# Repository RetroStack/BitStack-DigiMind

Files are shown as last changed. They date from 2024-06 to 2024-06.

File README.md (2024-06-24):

# DigiMind

As part of an introduction in digital electronics workshop at VCF SW 2024, I prepared this design of a Masterm\*nd like game to teach digital electronics.

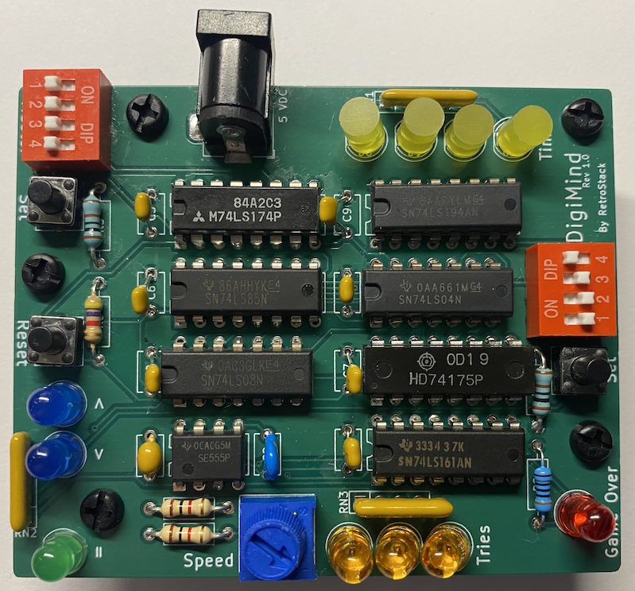
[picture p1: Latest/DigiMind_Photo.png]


## Latest Files

In the "Latest" folder, you'll find the most up-to-date design files, including:

- Gerber files suitable for popular online PCB manufacturers like [PCBWay](/Latest/DigiMind_Gerber_PCBWay.zip) and [JLCPCB](/Latest/DigiMind_Gerber_JLCPCB.zip). Most manufacturers should be fine with either.
- A Bill of Materials (BOM) in both [CSV](/Latest/DigiMind_BOM.csv) and [PDF](/Latest/DigiMind_BOM.pdf) formats.
- The [full schematics](/Latest/DigiMind_Schematics.pdf) of the board.

## Implementation

The board has been implemented using KiCAD 8. The KiCAD project files are included in this repository.

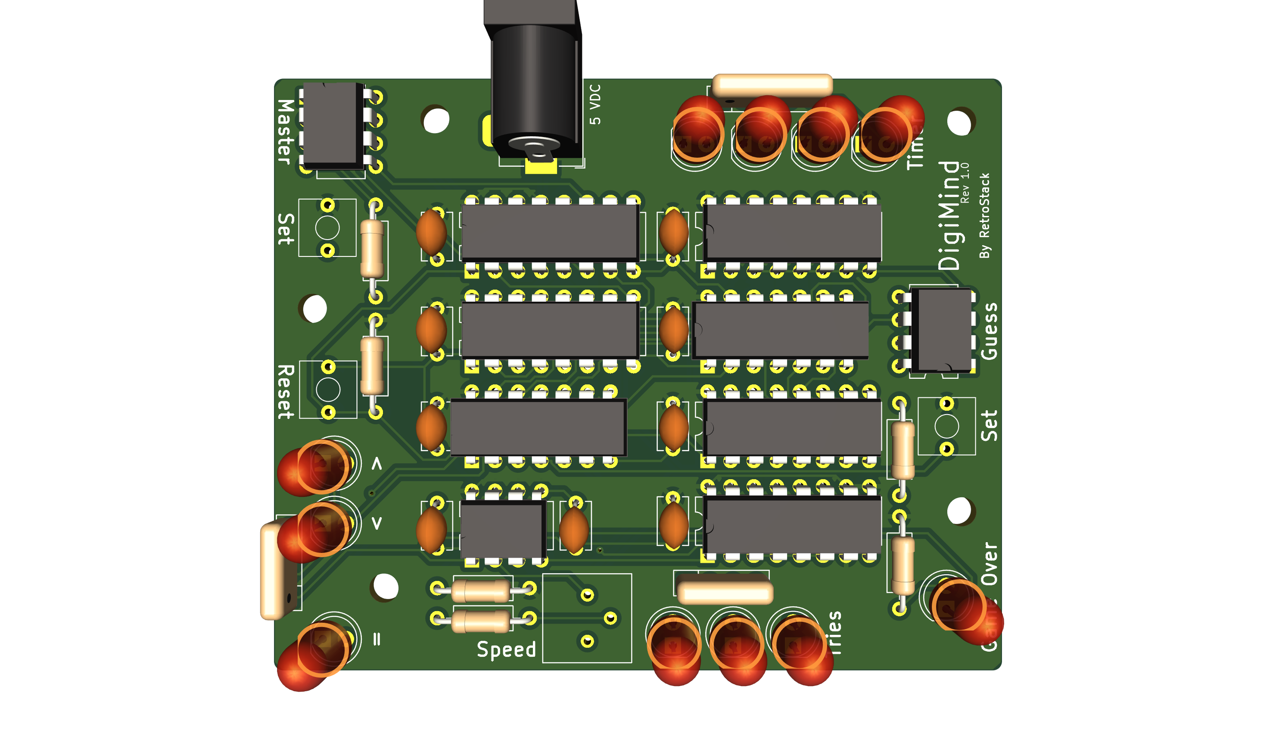
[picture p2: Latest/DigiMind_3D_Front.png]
Front

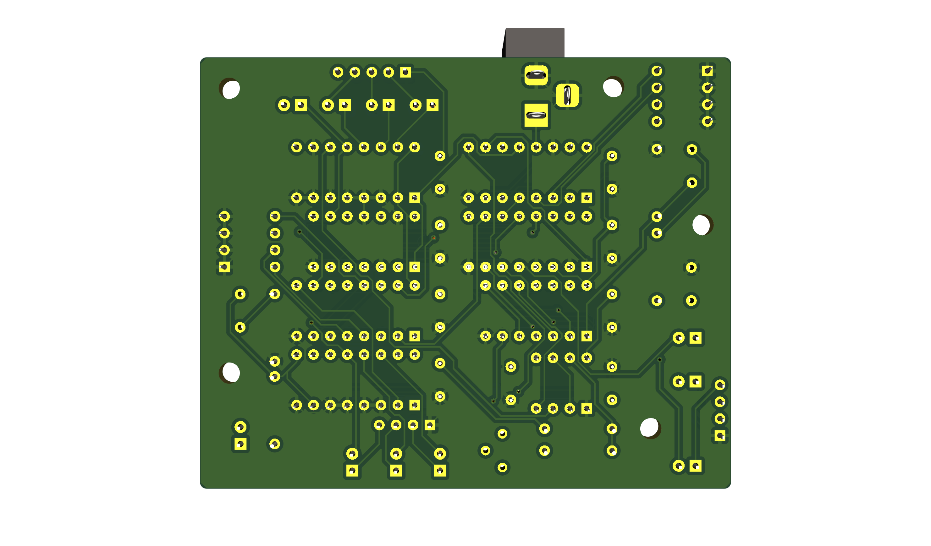
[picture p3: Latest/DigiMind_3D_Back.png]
Back


## How to Play

There are two players for this game:

- A person guessing the master code
- A person defining the master code

Before starting the game, the person defining the master code hits the "Reset" button to reset the game's state. Then, they enter the code using the DIP switches labeled "Master." When completed, the "Set" button must be pushed to set the master code. After that, the master code can be cleared from the DIP switches as it has been read into the memory.

As soon as the "Set" button is pressed, a timer labeled "Timer" starts running down. When the last light turns off, the game is over (if the master code was not found). The potentiometer labeled "Speed" can increase the time a player has to guess the master code.

The guesser needs to enter a code into the DIP switch on the other side, labeled "Guess." The "Set" button right next to it can be pressed to trigger a guess attempt. Each attempt is recognized and counted up with the "Tries" lights. When reaching a binary 8, the game is over.

In either case, when the time runs out or when 8 guesses have been made and the guess was wrong, the "Game Over" light indicates the game is over. This light will turn on regardless of whether the master code was found or not (to simplify the logic). What is important is the "=" light that indicates if the guess was correct.

If the guess was wrong, the board indicates if the master code is higher or lower than the entered guess. These indicators are labeled "<" and ">".

### Known Issues

Some decisions were made to keep the diagram somewhat readable for beginners. For example, the "Game Over" light will turn on regardless if the guess was found or not. There is also an issue when entering guesses where a bouncing of the "Set" button causes multiple guesses to register. This can be fixed by a debouncing circuit.

## Bill of Materials (BOM)

Below is a list of materials needed to assemble the PCB.

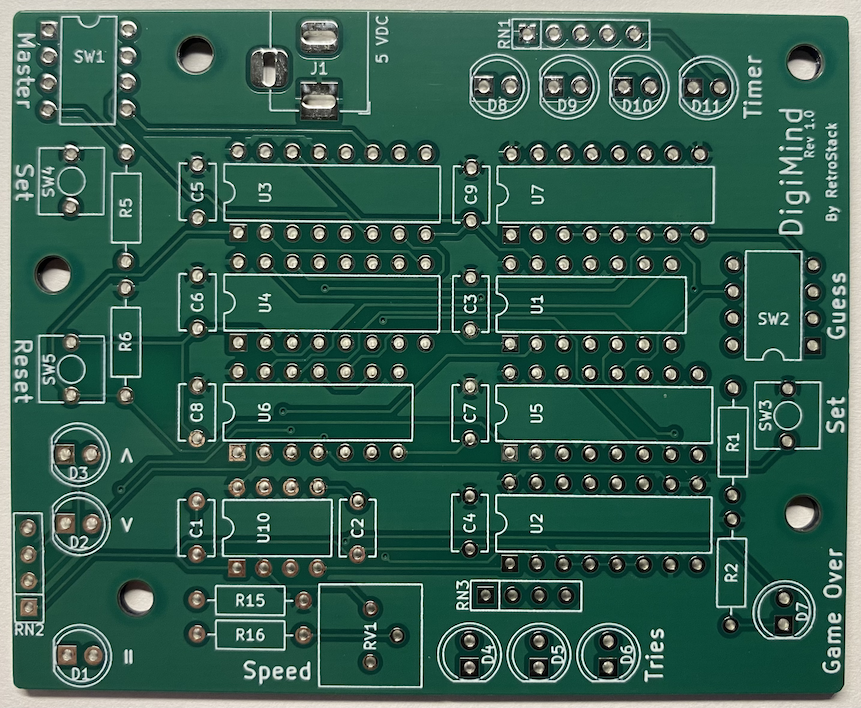
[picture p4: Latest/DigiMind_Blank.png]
Board


| Reference | Qty | Description | Footprint | Datasheet |
| --- | --- | --- | --- | --- |
| C1 | 1 | 10uF | Capacitor_THT:C_Disc_D5.1mm_W3.2mm_P5.00mm | ~ |
| C2 | 1 | 0.01uF | Capacitor_THT:C_Disc_D5.1mm_W3.2mm_P5.00mm | ~ |
| C3,C4,C5,C6,C7,C8,C9 | 7 | C | Capacitor_THT:C_Disc_D5.1mm_W3.2mm_P5.00mm | ~ |
| D1 | 1 | Green | LED_THT:LED_D5.0mm | ~ |
| D2,D3 | 2 | Yellow | LED_THT:LED_D5.0mm | ~ |
| D4,D5,D6,D7,D8,D9,D10,D11 | 8 | Red | LED_THT:LED_D5.0mm | ~ |
| J1 | 1 | Barrel_Jack_Switch | Connector_BarrelJack:BarrelJack_Horizontal | ~ |
| R1,R5,R6 | 3 | R | Resistor_THT:R_Axial_DIN0207_L6.3mm_D2.5mm_P10.16mm_Horizontal | ~ |
| R2,R15,R16 | 3 | 1k | Resistor_THT:R_Axial_DIN0207_L6.3mm_D2.5mm_P10.16mm_Horizontal | ~ |
| RN1 | 1 | R_Network04 | Resistor_THT:R_Array_SIP5 | http://www.vishay.com/docs/31509/csc.pdf |
| RN2,RN3 | 2 | R_Network03 | Resistor_THT:R_Array_SIP4 | http://www.vishay.com/docs/31509/csc.pdf |
| RV1 | 1 | 1M | Potentiometer_THT:Potentiometer_Bourns_3386P_Vertical | ~ |
| SW1,SW2 | 2 | SW_DIP_x04 | Package_DIP:DIP-8_W7.62mm | ~ |
| SW3,SW4,SW5 | 3 | SW_Push | RetroStackLibrary:SW_SPST_Push | ~ |
| U2 | 1 | 74LS161 | Package_DIP:DIP-16_W7.62mm | http://www.ti.com/lit/gpn/sn74LS161 |
| U3 | 1 | 74LS174 | Package_DIP:DIP-16_W7.62mm | http://www.ti.com/lit/gpn/sn74LS174 |
| U4 | 1 | 74LS85 | Package_DIP:DIP-16_W7.62mm | http://www.ti.com/lit/gpn/sn74LS85 |
| U5 | 1 | 74LS175 | Package_DIP:DIP-16_W7.62mm | http://www.ti.com/lit/gpn/sn74LS175 |
| U6 | 1 | 74LS08 | Package_DIP:DIP-14_W7.62mm | http://www.ti.com/lit/gpn/sn74LS08 |
| U7 | 1 | 74LS194 | Package_DIP:DIP-16_W7.62mm | http://www.ti.com/lit/gpn/sn74LS194 |
| U8 | 1 | 74LS02 | | http://www.ti.com/lit/gpn/sn74ls02 |
| U10 | 1 | NA555P | Package_DIP:DIP-8_W7.62mm | http://www.ti.com/lit/ds/symlink/ne555.pdf |

## RetroStack Libraries

To work with this KiCAD project, you'll need the RetroStack libraries for KiCAD. Please [follow this link](https://www.github.com/RetroStack/KiCAD-Libraries) to access and install these libraries.

## Support this Project

RetroStack is passionate about exploring and preserving the legacy of older computer systems. BitStack is a sub-project of RetroStack, focusing on education in digital electronics. My work involves creating detailed documentation and videos to share the knowledge. I am also dedicated to reviving these classic systems by reimplementing them and offering replacement parts at no cost. If you're keen on supporting this unique project, I invite you to visit my [Patreon page](https://www.patreon.com/RetroStack). Your support would be immensely valuable and greatly appreciated!

## License

This project is licensed under the MIT License - see the [LICENSE](LICENSE) file for details.

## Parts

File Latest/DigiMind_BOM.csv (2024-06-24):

Reference | Value | Datasheet | Footprint | Qty | DNP
C1 | 10uF | ~ | Capacitor_THT:C_Disc_D5.1mm_W3.2mm_P5.00mm | 1
C2 | 0.01uF | ~ | Capacitor_THT:C_Disc_D5.1mm_W3.2mm_P5.00mm | 1
C3,C4,C5,C6,C7,C8,C9 | C | ~ | Capacitor_THT:C_Disc_D5.1mm_W3.2mm_P5.00mm | 7
D1 | Green | ~ | LED_THT:LED_D5.0mm | 1
D2,D3 | Yellow | ~ | LED_THT:LED_D5.0mm | 2
D4,D5,D6,D7,D8,D9,D10,D11 | Red | ~ | LED_THT:LED_D5.0mm | 8
J1 | Barrel_Jack_Switch | ~ | Connector_BarrelJack:BarrelJack_Horizontal | 1
R1,R5,R6 | R | ~ | Resistor_THT:R_Axial_DIN0207_L6.3mm_D2.5mm_P10.16mm_Horizontal | 3
R2,R15,R16 | 1k | ~ | Resistor_THT:R_Axial_DIN0207_L6.3mm_D2.5mm_P10.16mm_Horizontal | 3
RN1 | R_Network04 | http://www.vishay.com/docs/31509/csc.pdf | Resistor_THT:R_Array_SIP5 | 1
RN2,RN3 | R_Network03 | http://www.vishay.com/docs/31509/csc.pdf | Resistor_THT:R_Array_SIP4 | 2
RV1 | 1M | ~ | Potentiometer_THT:Potentiometer_Bourns_3386P_Vertical | 1
SW1,SW2 | SW_DIP_x04 | ~ | Package_DIP:DIP-8_W7.62mm | 2
SW3,SW4,SW5 | SW_Push | ~ | RetroStackLibrary:SW_SPST_Push | 3
U2 | 74LS161 | http://www.ti.com/lit/gpn/sn74LS161 | Package_DIP:DIP-16_W7.62mm | 1
U3 | 74LS174 | http://www.ti.com/lit/gpn/sn74LS174 | Package_DIP:DIP-16_W7.62mm | 1
U4 | 74LS85 | http://www.ti.com/lit/gpn/sn74LS85 | Package_DIP:DIP-16_W7.62mm | 1
U5 | 74LS175 | http://www.ti.com/lit/gpn/sn74LS175 | Package_DIP:DIP-16_W7.62mm | 1
U6 | 74LS08 | http://www.ti.com/lit/gpn/sn74LS08 | Package_DIP:DIP-14_W7.62mm | 1
U7 | 74LS194 | http://www.ti.com/lit/gpn/sn74LS194 | Package_DIP:DIP-16_W7.62mm | 1
U8 | 74LS02 | http://www.ti.com/lit/gpn/sn74ls02 |  | 1
U10 | NA555P | http://www.ti.com/lit/ds/symlink/ne555.pdf | Package_DIP:DIP-8_W7.62mm | 1

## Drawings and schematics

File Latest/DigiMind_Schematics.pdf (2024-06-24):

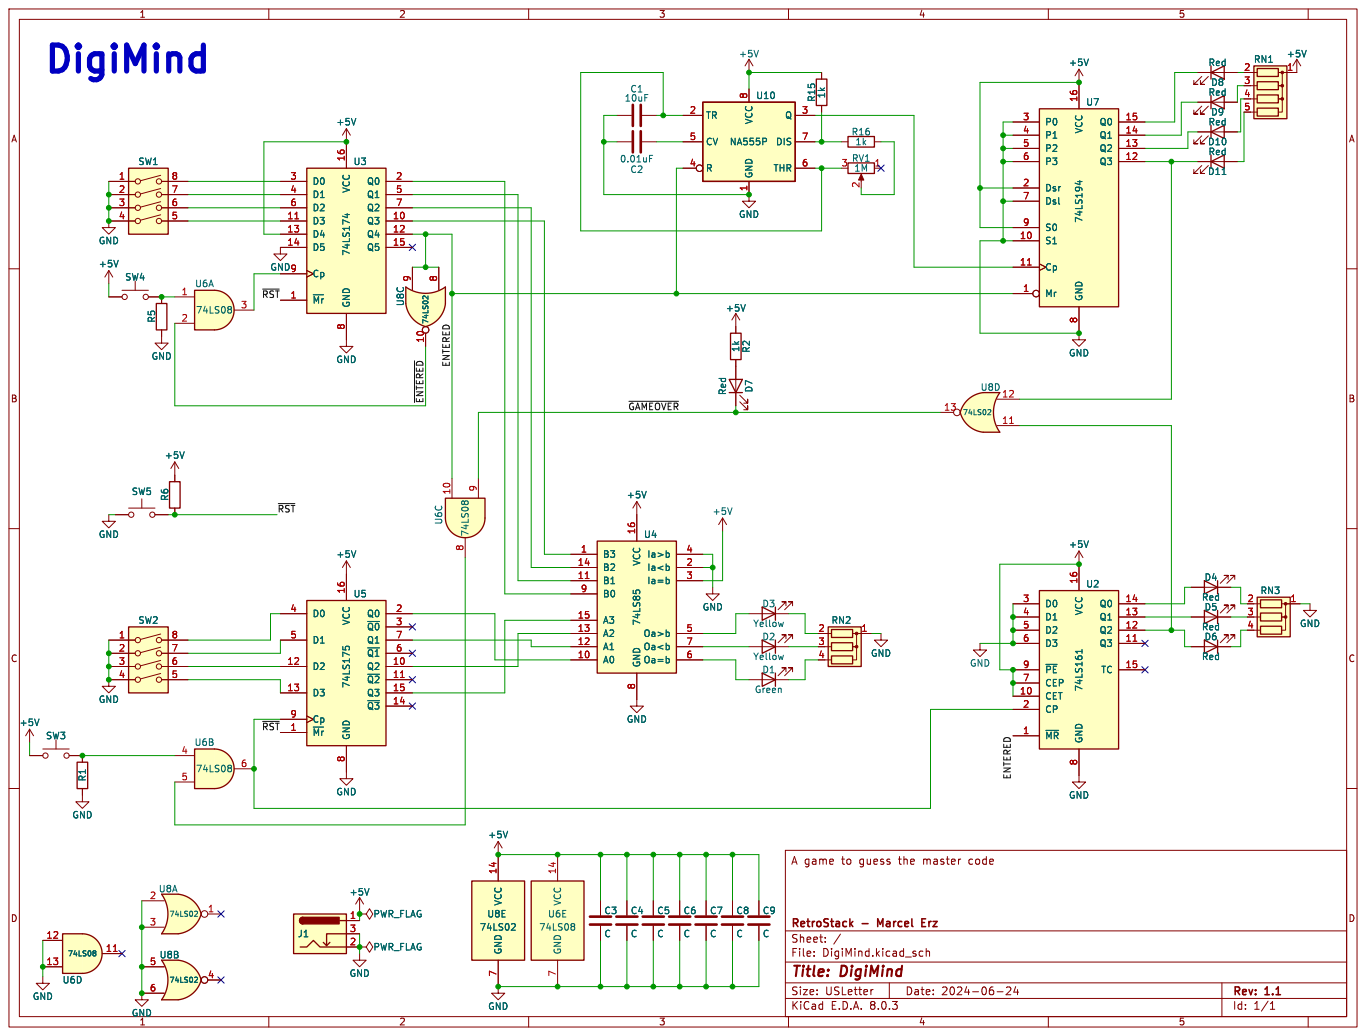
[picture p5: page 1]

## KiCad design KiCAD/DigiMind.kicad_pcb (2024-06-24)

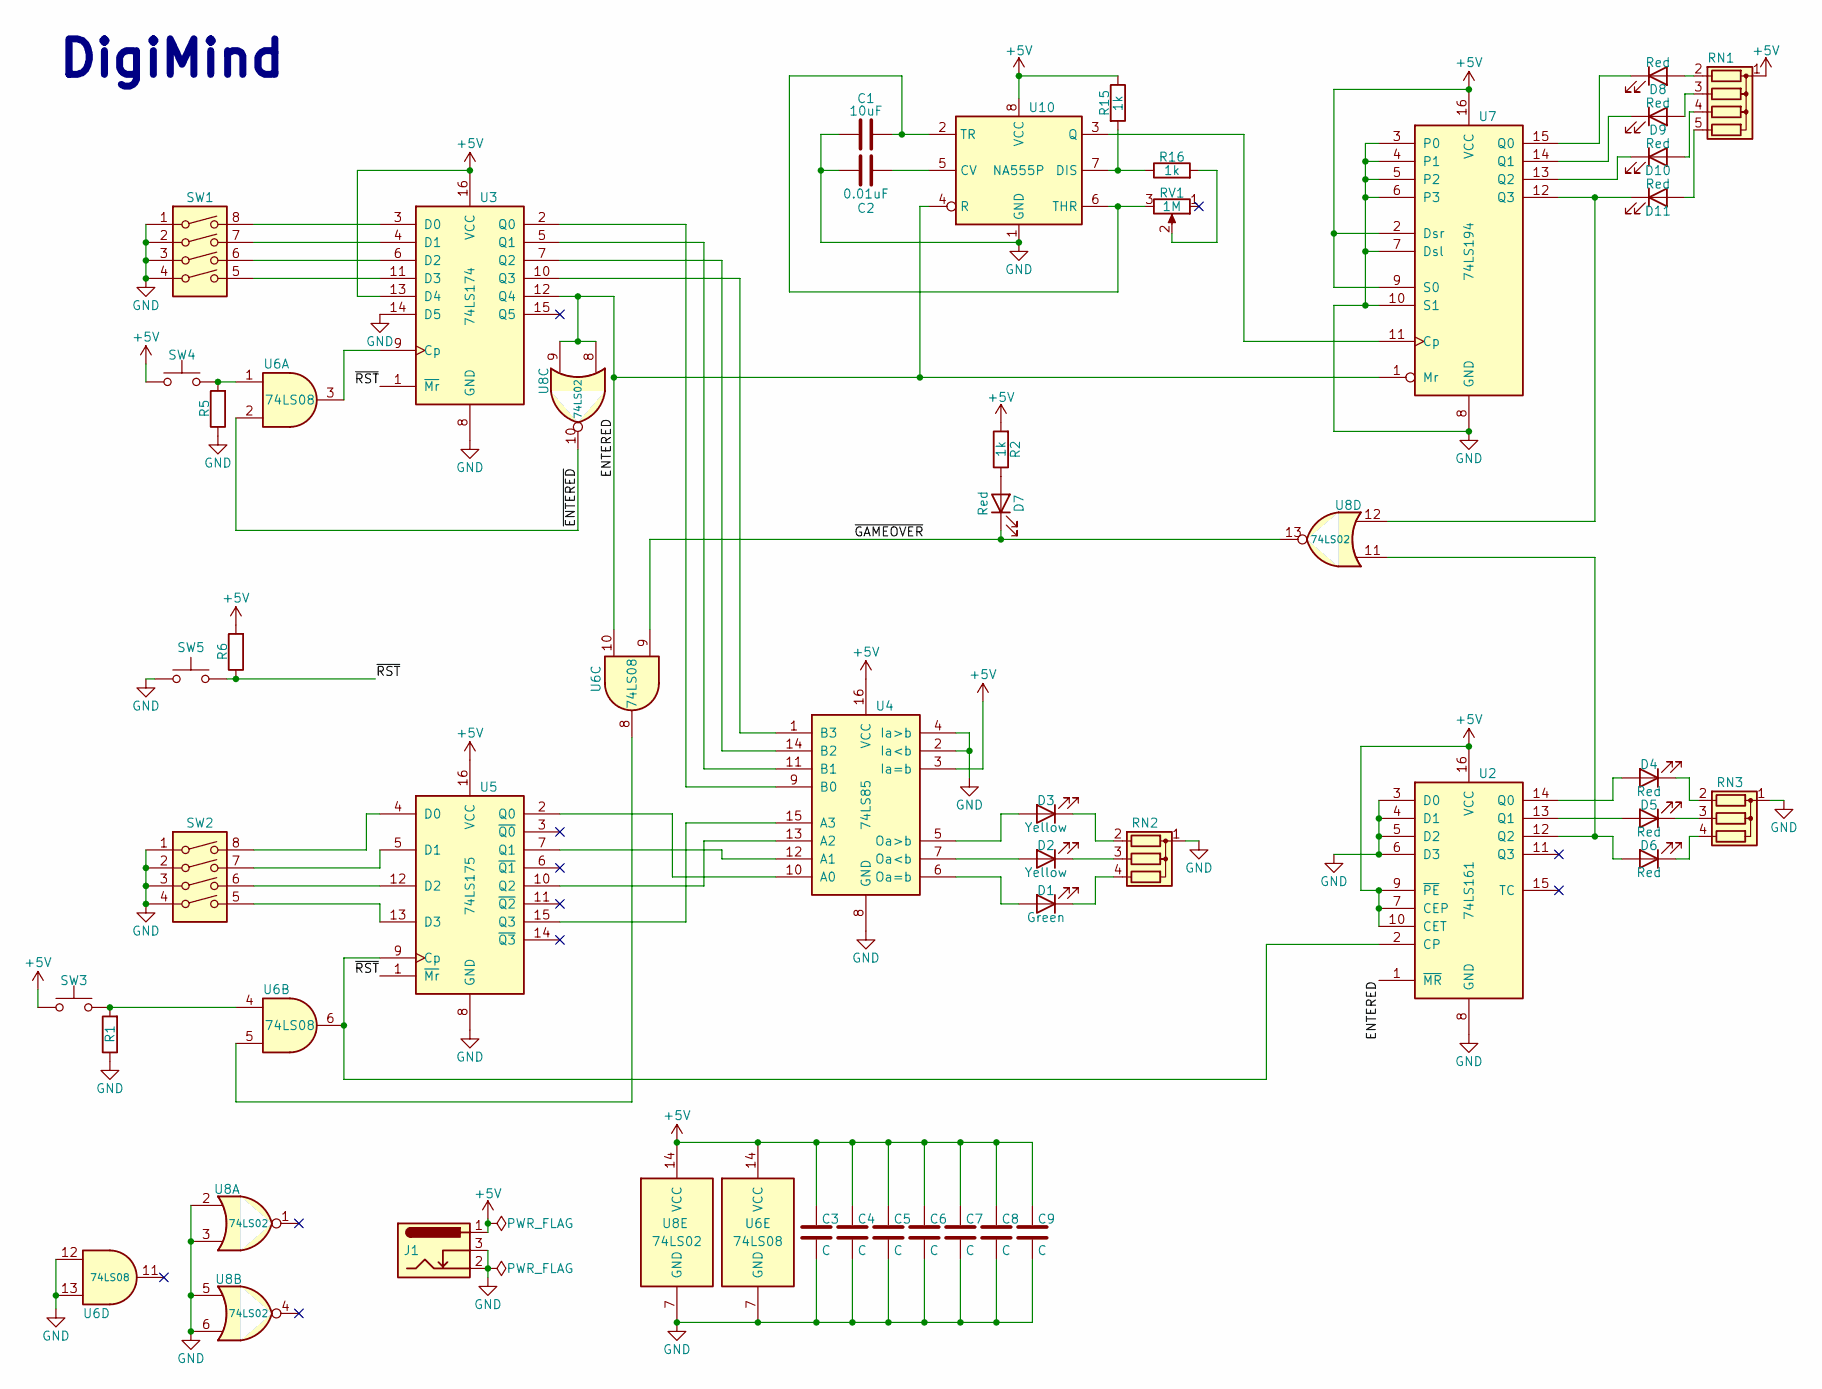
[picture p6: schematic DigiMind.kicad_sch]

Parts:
C1: 10uF; C_Disc_D5.1mm_W3.2mm_P5.00mm
C2: 0.01uF; C_Disc_D5.1mm_W3.2mm_P5.00mm
C3, C4, C5, C6, C7, C8, C9: C; C_Disc_D5.1mm_W3.2mm_P5.00mm
D1: Green; LED_D5.0mm
D2, D3: Yellow; LED_D5.0mm
D4, D5, D6, D7, D8, D9, D10, D11: Red; LED_D5.0mm
J1: Barrel_Jack_Switch; BarrelJack_Horizontal
R1, R5, R6: R; R_Axial_DIN0207_L6.3mm_D2.5mm_P10.16mm_Horizontal
R2, R15, R16: 1k; R_Axial_DIN0207_L6.3mm_D2.5mm_P10.16mm_Horizontal
RN1: R_Network04; R_Array_SIP5
RN2, RN3: R_Network03; R_Array_SIP4
RV1: 1M; Potentiometer_Bourns_3386P_Vertical
SW1, SW2: SW_DIP_x04; DIP-8_W7.62mm
SW3, SW4, SW5: SW_Push; SW_SPST_Push
U2: 74LS161; DIP-16_W7.62mm
U3: 74LS174; DIP-16_W7.62mm
U4: 74LS85; DIP-16_W7.62mm
U5: 74LS175; DIP-16_W7.62mm
U6: 74LS08; DIP-14_W7.62mm
U7: 74LS194; DIP-16_W7.62mm
U8: 74LS02
U10: NA555P; DIP-8_W7.62mm

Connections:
+5V: C3.1, C4.1, C5.1, C6.1, C7.1, C8.1, C9.1, J1.1, R2.2, R6.2, R15.1, RN1.1 (common), SW3.1, SW4.1, U2.7 (CEP), U2.9 (~PE), U2.10 (CET), U2.16 (VCC), U3.13 (D4), U3.16 (VCC), U4.3 (Ia=b), U4.16 (VCC), U5.16 (VCC), U6.14 (VCC), U7.2 (Dsr), U7.9 (S0), U7.16 (VCC), U8.14 (VCC), U10.8 (VCC); also elsewhere on the board
/ENTERED: U2.1 (~MR), U3.12 (Q4), U6.10, U7.1 (Mr), U8.8, U8.9, U10.4 (R); also elsewhere on the board
/~ENTERED: U6.2, U8.10; also elsewhere on the board
/~GAMEOVER: D7.1 (K), U6.9, U6.11, U8.13
/~RST: R6.1, SW5.2, U3.1 (~Mr), U5.1 (~Mr)
unnamed: D1.2 (A), U4.6 (Oa=b)
unnamed: D1.1 (K), RN2.4 (R3)
unnamed: D2.2 (A), U4.7 (Oa<b)
unnamed: D2.1 (K), RN2.3 (R2)
unnamed: D3.2 (A), U4.5 (Oa>b)
unnamed: D3.1 (K), RN2.2 (R1)
unnamed: D4.2 (A), U2.14 (Q0)
unnamed: D4.1 (K), RN3.2 (R1)
unnamed: D5.2 (A), U2.13 (Q1)
unnamed: D5.1 (K), RN3.3 (R2)
unnamed 15: D6.2 (A), U2.12 (Q2), U8.11; also elsewhere on the board
unnamed: D6.1 (K), RN3.4 (R3)
unnamed: D7.2 (A), R2.1
unnamed: D8.2 (A), RN1.2 (R1)
unnamed: D8.1 (K), U7.15 (Q0)
unnamed: D9.2 (A), RN1.3 (R2)
unnamed: D9.1 (K), U7.14 (Q1)
unnamed: D10.2 (A), RN1.4 (R3)
unnamed: D10.1 (K), U7.13 (Q2)
unnamed: D11.2 (A), RN1.5 (R4)
unnamed 25: D11.1 (K), U7.12 (Q3), U8.12; also elsewhere on the board
unnamed: R1.2, SW3.2, U6.4
unnamed: R5.2, SW4.2, U6.1
unnamed: R16.2, RV1.2
unnamed: U2.2 (CP), U5.9 (Cp), U6.6
unnamed: U3.9 (Cp), U6.3
unnamed: SW1.8, U3.3 (D0)
unnamed: SW1.7, U3.4 (D1)
unnamed: SW1.6, U3.6 (D2)
unnamed: SW1.5, U3.11 (D3)
unnamed: U3.2 (Q0), U4.9 (B0)
unnamed: U3.5 (Q1), U4.11 (B1)
unnamed: U3.7 (Q2), U4.14 (B2)
unnamed: U3.10 (Q3), U4.1 (B3)
unnamed: U4.10 (A0), U5.2 (Q0)
unnamed: U4.12 (A1), U5.7 (Q1)
unnamed: U4.13 (A2), U5.10 (Q2)
unnamed: U4.15 (A3), U5.15 (Q3)
unnamed: SW2.8, U5.4 (D0)
unnamed: SW2.7, U5.5 (D1)
unnamed: SW2.6, U5.12 (D2)
unnamed: SW2.5, U5.13 (D3)
unnamed: U6.5, U6.8
unnamed: C2.2, U10.5 (CV)
unnamed: R15.2, R16.1, U10.7 (DIS)
unnamed: U7.11 (Cp), U10.3 (Q)
unnamed: C1.2, RV1.3, U10.2 (TR), U10.6 (THR)

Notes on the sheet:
DigiMind

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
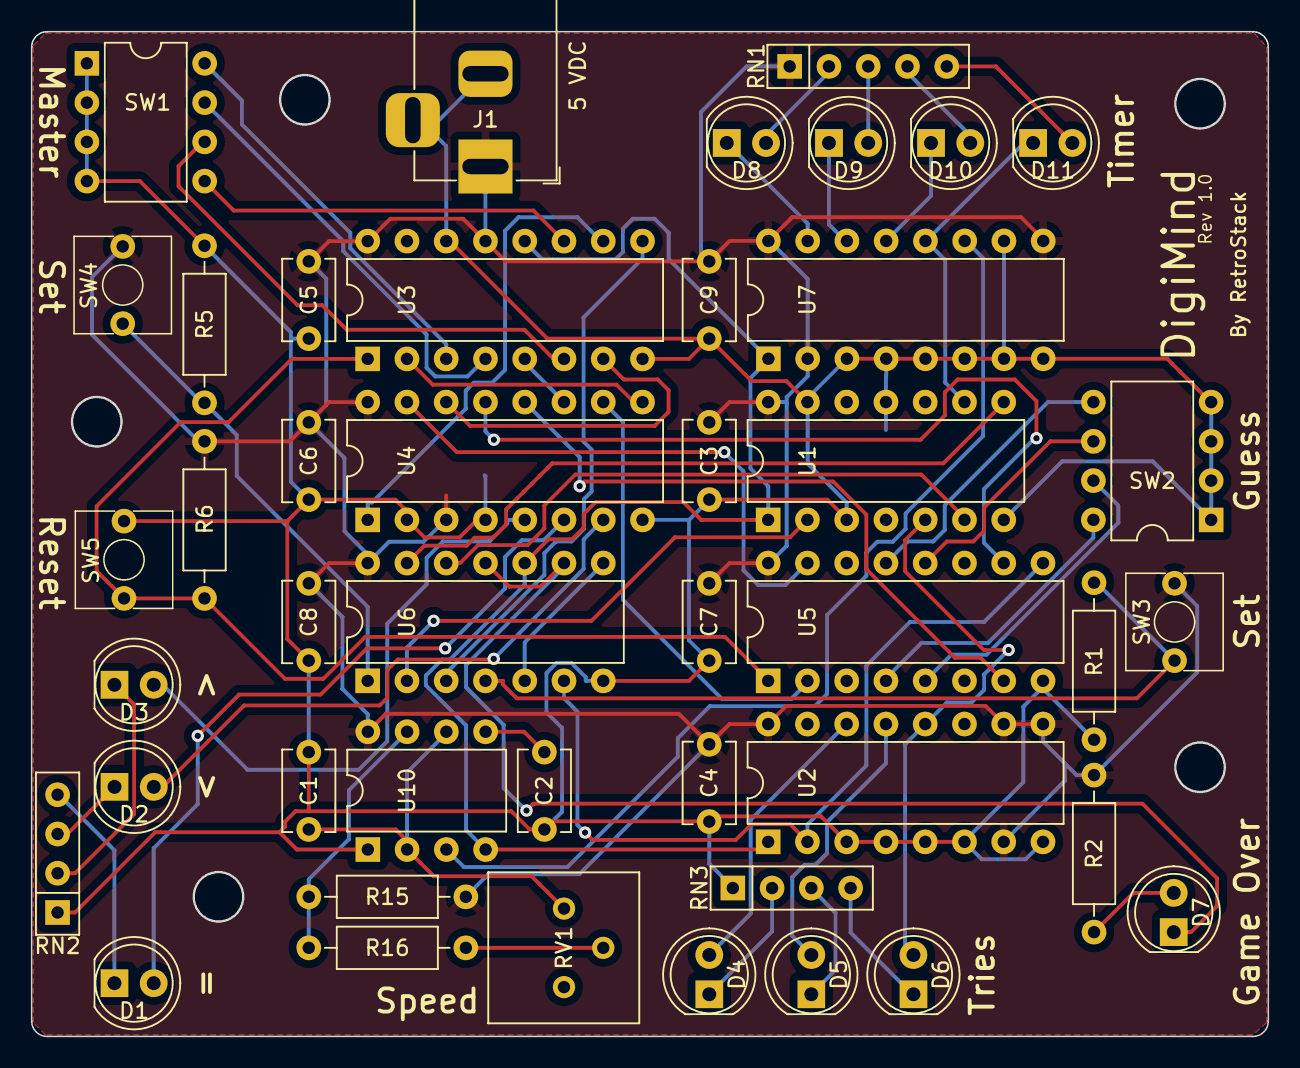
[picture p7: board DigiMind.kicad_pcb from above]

Board: 2 copper layers, 80.0 x 65.0 mm, 44 parts (0 on the bottom side), 55 nets.

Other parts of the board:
U1: 74LS04; DIP-14_W7.62mm

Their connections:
+5V: U1.14 (VCC); also elsewhere on the board
/ENTERED: U1.1; also elsewhere on the board
/~ENTERED: U1.2; also elsewhere on the board
unnamed 15: U1.5; also elsewhere on the board
unnamed 25: U1.9; also elsewhere on the board

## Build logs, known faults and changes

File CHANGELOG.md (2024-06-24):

# DigiMind - Changelog

## 24th June 2024 - Rev 1.0

Completed test. Fully functional.
